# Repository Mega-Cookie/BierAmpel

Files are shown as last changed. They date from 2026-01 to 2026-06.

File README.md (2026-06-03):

# BierAmpel



Dokumentation der Projekarbeit im Lernfeld 7 der Gruppe 3.

## Gruppemitglieder
* Ahmed
* Ben
* Kevin
* Lucas
* Michael
* Zenon

## Wir brauchen:
1. Eine Kühlbox 
    - Müsste ich noch haben.

1. Drucksensoren (HX711) am Boden 
    - Ist genug Bier da?
    - Sind mit Halterungen aus dem 3D-Drucker ein einem Brett befestigt.
        - [Printables](https://www.printables.com/model/157473-load-cell-holder)
    - [Amazon](https://www.amazon.de/Menschlichen-Gewichtungssensor-Verst%C3%A4rker-Dehnungsmessger%C3%A4t-Badezimmerwaage/dp/B07FMN1DBN)

1. Temparatursensor (ENOPYO 1M) in der Kühlbox 
    - Ist das Bier kalt
    - Ist in einer kleinen Glasflasche mit Wasser um Temperatur einer Flüsigkeit in der Kühlbox zu messen.
    - [Amazon](https://www.amazon.de/Temperatursensor-ENOPYO-Wasserdichte-Temperaturf%C3%BChler-Temperaturkabel/dp/B0DPKHDMHH)

1. Helligkeitssensor (DollaTek Digitales Licht Intensitätssensormodul) in der Kühlbox 
    - Ist die Box offen?
    - Empfindilichkeit kann über Drehregler eingestellt werden.
    - [Amazon](https://www.amazon.de/DollaTek-Digitales-Intensit%C3%A4tssensormodul-Fotowiderstand-Photowiderstand/dp/B07DJ4WQV5)

1. Eine kleine Ampel aus LEDs 
    - Ist Bier zum Trinken Bereit?
    - LEDs in den nötigen Farben habe ich.
    - Eine Ampel je Sensor + eine Ampel für den schlechtesten Wert.
    - Gehäuse kann ich drucken.
        - [Printables](https://www.printables.com/model/420231-traffic-light-for-arduino-ampel-fur-arduino)

1. Alarm Buzzer 
    - Ist die Box zu Lange offen?
    - Geht nach 30 Sekunden los wenn der Deckel auf ist.
    - Buzzer habe ich. 
        - Alternativ Lautsprecher am RPi spielt einen Alarmton ab.

1. RaspberryPi
    - RPi5 wurde vom Betrieb gestellt
    - Sammelt die Daten
    - Sendet an MQTT (bzw. stellt selbst den MQTT Broker)
    - Steuert die Ampeln

1. Arduino
    - Arduino Nano ist vorhanden
    - Liest die Sensoren aus
    - sendet über USB die Daten an den RPi
    - Steuert den Buzzer

## Umsetzung
* Die Umgebungstemperatur holen vom MQTT Broker von Herrn Mierwald.
* Die Sensoren sind an einen Arduino angeschlossen.
* Die Daten wernden über das USB-Kabel (Serial) an den RaspberryPi geschickt.
* Aus den Sensoren kann die Temperatur und der Menge an Bier (Gewicht/Gewicht einer Bierdose) ermittelt werden.
* RaspberryPi gesammelt die Daten und steuert über ein Python Script die Ampeln.
* Im selben Script werden die Daten and den MQTT Broker gesendet.

## Kosten
| Posten | Summe |
|:---|---:|
|Gewichtssensor  | 7,89€|
|Temperatursensor| 4,99€|
|Lichtsensor | 4,99€|
|**Gesamt** | **17,96€**|

Kosten für Kleinteile wie Kabel, LEDs, und PLA, sowie den Arduino werden vernachlässigt, da diese sowieso vorhanden sind.

## Nutzung

### Download
Die Binary kann aus dem [GitHub Release](https://github.com/Mega-Cookie/BierAmpel/releases/latest) runtergeladen werden:

```
wget https://github.com/Mega-Cookie/BierAmpel/releases/latest/download/BierAmpel-arm64rpi5
```

### Binary starten

Die entsprechenden <Übergabeparameter> müssen angegeben werden, andernsfalls werden [Defaultwerte] verwendet.

Für den Zugriff auf das Serial Interface sind in Regel `root`-Rechete nötig. Die Binary muss also als `root` oder mit `sudo` ausgeführt werden.

```
sudo ./BierAmpel-arm64rpi5 \
--boker <MQTT broker adress> \ [localhost] # localhost requires a configured MQTT broker.
--port <MQTT broker port> \ [1883]
--user <MQTT user> \
--pass <MQTT password> \
--serial <serial port> \ [/dev/ttyACM0] # default set to ttyACM0 for dev. On RPI it should be ttyUSB0
--env <ambient temp MQTT topic> [env/temp] # default set to env/temp for dev.
```

## Schaltkreis
### LEDs
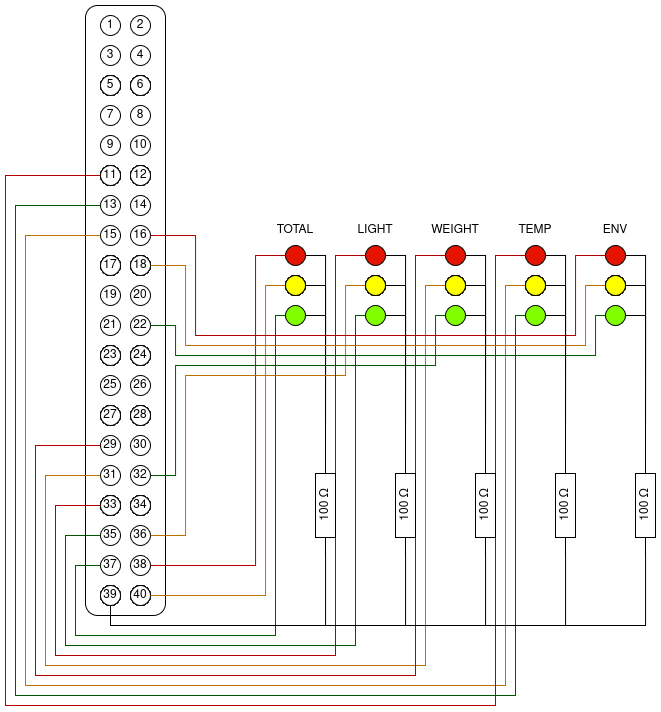
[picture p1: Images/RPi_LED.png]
RPi pin population

### Sensoren
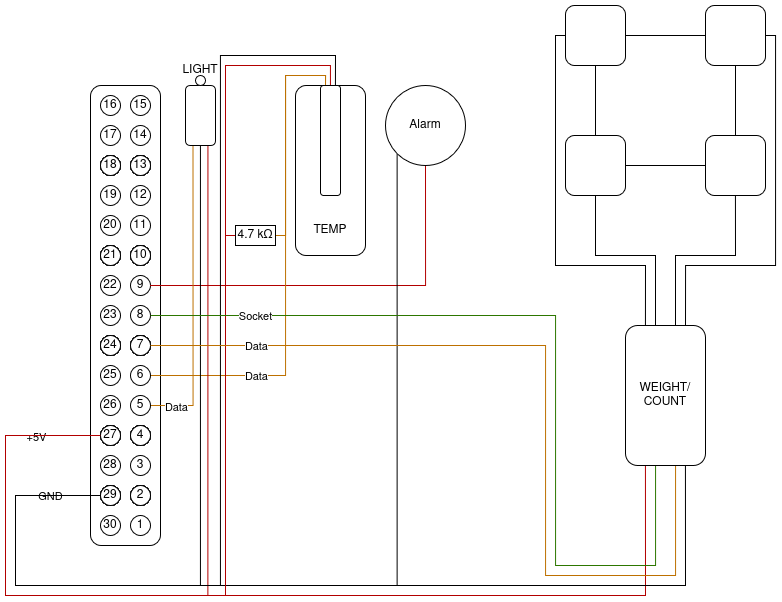
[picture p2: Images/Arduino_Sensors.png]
Arduino pin population


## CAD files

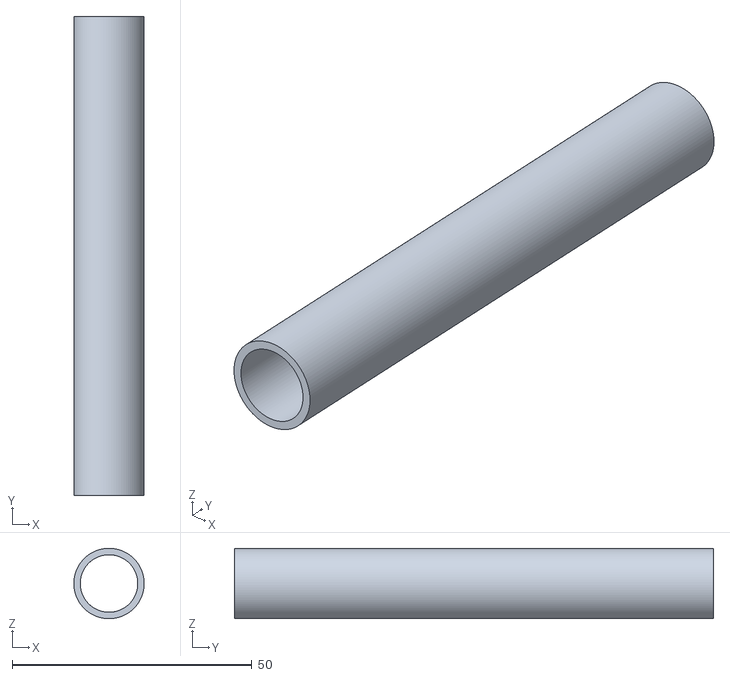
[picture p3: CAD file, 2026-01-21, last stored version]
3dPrints/Rohr10mm.stl
14.7 x 100.0 x 14.7

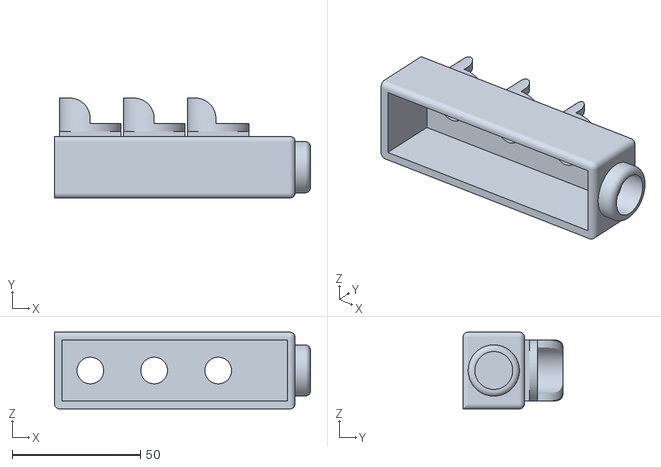
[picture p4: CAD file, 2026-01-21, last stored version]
3dPrints/Ampel10mm.stl
100.0 x 39.0 x 30.0

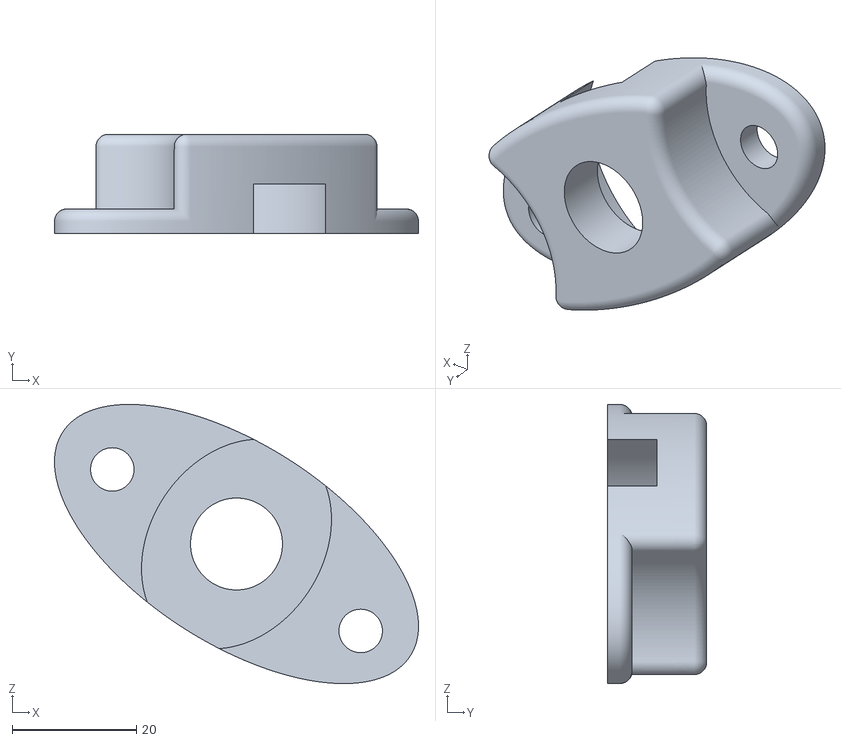
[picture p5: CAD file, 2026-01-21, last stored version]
3dPrints/Ampelfuss10mm.stl
58.6 x 16.0 x 45.0

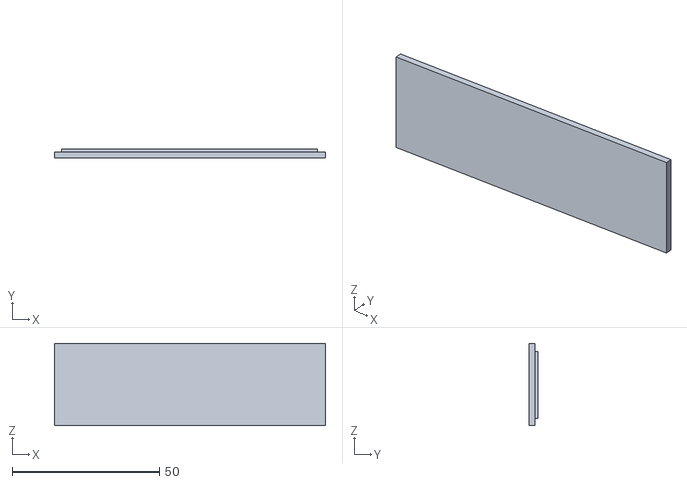
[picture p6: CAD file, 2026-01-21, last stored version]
3dPrints/Ampel_Deckel10mm.stl
92.0 x 3.00 x 28.0

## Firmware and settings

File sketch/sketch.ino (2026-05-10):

#include <OneWire.h>
#include <DallasTemperature.h>
#include <HX711.h>

unsigned long lastTime = 0;
const unsigned long interval = 1000;
const int threshold = 30;
const int lightPin = 2;

int trigger = 0;
int alarm = 0;

#define ONE_WIRE_BUS 3
OneWire oneWire(ONE_WIRE_BUS);
DallasTemperature sensors(&oneWire);

const int DOUT_PIN = 4;
const int SCK_PIN = 5;
HX711 scale;

const int buzzPin = 6;

void setup() {
  Serial.begin(9600);
  piSerial.begin(9600);
  pinMode(lightPin, INPUT);
  pinMode(buzzPin, OUTPUT);
  digitalWrite(buzzPin, LOW);
  scale.begin(DOUT_PIN, SCK_PIN);
  scale.set_scale(24);
  delay(500);
  scale.tare();
  sensors.begin();
}

void multiPrint(String message) {
  Serial.print(message);   // Print to USB
  piSerial.print(message); // Print to GPIO
}

void loop() {
  unsigned long currentTime = millis();
  if (currentTime - lastTime >= interval) {
    lastTime = currentTime;
    int lightState = !digitalRead(lightPin);
        if (lightState == 1) {
      trigger++;
    } else {
      trigger=0;
    }
    if (trigger >= threshold) {
      alarm = 1;
      digitalWrite(buzzPin, HIGH);
    } else {
      alarm = 0;
      digitalWrite(buzzPin, LOW);
    }

    sensors.requestTemperatures();
    float tempCelsius = sensors.getTempCByIndex(0);

    if (scale.is_ready()) {
      multiPrint("Gewicht:" + String(scale.get_units(), 0) + ",");
    } else {
      multiPrint("Gewicht: 0,");
    }
    multiPrint("Licht:" + String(lightState) + ",");
    multiPrint("Alarm:" + String(alarm) + ",");
    multiPrint("Temperatur:" + String(tempCelsius) + "\n");
  }  
}

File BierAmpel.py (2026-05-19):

#! /bin/env python3
from gpiozero import LEDBoard, Device
from gpiozero.pins.lgpio import LGPIOFactory
import argparse
import serial
from time import sleep
import sys
import logging
import signal
import paho.mqtt.client as mqtt
import paho.mqtt.publish as publish

Device.pin_factory = LGPIOFactory()

# Logging
logging.basicConfig(
    level=logging.INFO,
    format='%(asctime)s - %(levelname)s - %(message)s',
    handlers=[
        logging.FileHandler("bierampel.log"),
        logging.StreamHandler(sys.__stdout__)
    ]
)

logger = logging.getLogger(__name__)
file_logger = logging.getLogger("OnlyFile")
file_logger.propagate = False # Verhindert, dass die Nachricht an die Konsole weitergereicht wird
file_handler = logging.FileHandler("bierampel.log")
file_handler.setFormatter(logging.Formatter('%(asctime)s - %(message)s'))
file_logger.addHandler(file_handler)

class StreamToLogger:
    def __init__(self, logger, log_level):
        self.logger = logger
        self.log_level = log_level
        self.linebuf = ''

    def write(self, buf):
        for line in buf.rstrip().splitlines():
            self.logger.log(self.log_level, line.rstrip())

    def flush(self):
        pass

sys.stdout = StreamToLogger(logging.getLogger('STDOUT'), logging.INFO)
sys.stderr = StreamToLogger(logging.getLogger('STDERR'), logging.ERROR)

# Funktionen
def ledtest():
    print("LED Test")
    # LED Test
    # cycle
    for name in led_order:
        led = getattr(leds, name)
        led.on()
        sleep(0.75)
        led.off()
    print("LED Test fertig")

def cleanup_and_exit(sig, frame):
    print("Beende Monitoring...")
    
    # 1. LEDs abschalten
    leds.close()
    print("LEDs abgschalten.")

    # 2. MQTT sauber trennen
    client.loop_stop()
    client.disconnect()
    print("MQTT-Verbindung getrennt.")
    
    # 3. Seriellen Port schließen
    if ser.is_open:
        ser.close()
    print("Serielle Schnittstelle geschlossen.")
    
    sys.exit(0)

signal.signal(signal.SIGINT, cleanup_and_exit)
signal.signal(signal.SIGTERM, cleanup_and_exit)

def ledswitch(sensor, state):
    state_map = {0: "OK", 1: "WARN", 2: "CRIT"}
    suffix = state_map.get(state)
    if suffix:
        sensor_name = f"{sensor}{suffix}"
        led_obj = getattr(leds, sensor_name)
        led_obj.on()
        file_logger.info(sensor_name)

env_data = float(0)
def on_message(client, userdata, msg):
    global env_data
    env_data = float(msg.payload.decode())

# Define LED Pins
sensor_state_map = {0: "weight", 1: "light", 2: "temp", 3: "env", 4: "total"}
led_order = [
    'totalOK', 'totalWARN', 'totalCRIT',
    'lightOK', 'lightWARN', 'lightCRIT',
    'weightOK', 'weightWARN', 'weightCRIT',
    'tempOK', 'tempWARN', 'tempCRIT',
    'envOK', 'envWARN', 'envCRIT'
]
leds = LEDBoard(
    totalOK = 26,
    totalWARN = 21,
    totalCRIT = 20,
    lightOK = 19,
    lightWARN = 16,
    lightCRIT = 13,
    weightOK = 12,
    weightWARN = 6,
    weightCRIT = 5,
    tempOK = 27,
    tempWARN = 22,
    tempCRIT= 17,
    envOK = 25,
    envWARN = 24,
    envCRIT = 23
)

# Input arguments
parser = argparse.ArgumentParser(description="Arduino to MQTT Script")

parser.add_argument("--serial", default="/dev/ttyACM0", help="Arduino serial port")
parser.add_argument("--baud", default=9600, help="Serial Baud rate")

parser.add_argument("--broker", default="localhost", help="MQTT broker IP address")
parser.add_argument("--port", default=1883, help="MQTT broker port")
parser.add_argument("--user", help="MQTT broker User")
parser.add_argument("--pass", dest="password", help="MQTT broker Password")

parser.add_argument("--env", default="env/temp", help="MQTT topic for environment data")

args = parser.parse_args()

SERIAL_PORT = args.serial
BAUD_RATE = args.baud

MQTT_BROKER = args.broker
MQTT_PORT = args.port
mqtt_auth = {
    "username": args.user,
    "password": args.password
}
env_topic = args.env

# Connect to MQTT
client = mqtt.Client(mqtt.CallbackAPIVersion.VERSION2)
client.username_pw_set(mqtt_auth["username"], mqtt_auth["password"])
client.on_message = on_message
client.connect(MQTT_BROKER, MQTT_PORT)
client.subscribe(env_topic)
client.loop_start()
print("Mit MQTT Broker verbunden")

state = [0,0,0,0,0]
unit = int(500)

# Connect to Serial
ser = serial.Serial(SERIAL_PORT, BAUD_RATE, timeout=1)
sleep(2)
print("Mit Arduino über Serial verbunden")

ledtest()
sleep(1)

print("Start monitoring...")
# Read Sensors, Switch LEDs, Send MQTT
try:
    while True:
        if ser.in_waiting > 0:
            line = ser.readline().decode("utf-8").strip()
            data = line.split(",")
            data = [
                float(item.split(":")[1]) for item in data
            ]
            data = [
                int(v) if v.is_integer() else v for v in data
            ]
            count = round(data[0]/unit, 0)
            if count <= 2:
                if count < 1:
                    state[0] = 2
                else:
                    state[0] = 1
            else:
                state[0] = 0

            if data[1] == 1:
                state[1] = 1
            else:
                state[1] = 0

            if data[3] > 15:
                if data[3] > 20:
                    state[2] = 2
                else:
                    state[2] = 1
            else:
                state[2] = 0
            if env_data < 18:
                if env_data < 16:
                    state[3] = 2
                else:
                    state[3] = 1
            else:
                state[3] = 0
            if data[2] == 1:
                for i in range(len(state)):
                    state[i] = 2
            state[4] = max(state[0:4])

            for led in leds:
                led.off()

            for i in range(0,5,1):
                ledswitch(sensor_state_map.get(i), state[i])

            topics_payloads = [
                ("bierampel/weight/sensor", data[0]),
                ("bierampel/weight/count", count),
                ("bierampel/weight/state", state[0]),
                ("bierampel/light/sensor", data[1]),
                ("bierampel/light/alarm", data[2]),
                ("bierampel/light/state", state[1]),
                ("bierampel/temp/sensor", data[3]),
                ("bierampel/temp/state", state[2]),
                ("bierampel/env/state", state[3]),
                ("bierampel/worst/state", state[4])
            ]
            msgs = [
                {"topic": topic, "payload": payload} for topic, payload in topics_payloads
            ]
            publish.multiple(msgs, hostname=MQTT_BROKER, auth=mqtt_auth)
except Exception as e:
    print(f"Fehler: {e}")
    cleanup_and_exit(None, None)

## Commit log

2026-01-22 Initial implimentation of new sensors
2026-01-24 force 1sec loop, add light triggered buzzer alarm
    [sketch.ino]
2026-01-25 add total state OK LED switch
2026-01-27 add more LED logic
2026-01-27 rework LED control
2026-01-27 remove unused stuff
    [Ampel10mm.stl, Ampel_Deckel10mm.stl, Ampelfuss10mm.stl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]
2026-01-28 rework LED switcher
2026-01-31 move and fix arduino sketch
    [sketch.ino]
2026-04-29 move led test to function
2026-04-29 redirect prints to log
2026-05-03 fix log to file
    [BierAmpel.py]
2026-05-10 refactor LED test
2026-05-19 update LED circuit
